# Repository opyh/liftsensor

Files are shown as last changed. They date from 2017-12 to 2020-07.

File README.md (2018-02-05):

# liftsensor

Measures acceleration to find out if an elevator works and updates its status on [accessibility.cloud](https://www.accessibility.cloud).

## Design / photos

This is how the sensor looks:

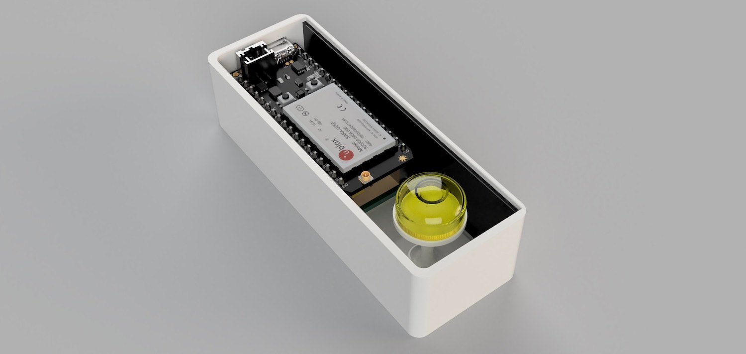
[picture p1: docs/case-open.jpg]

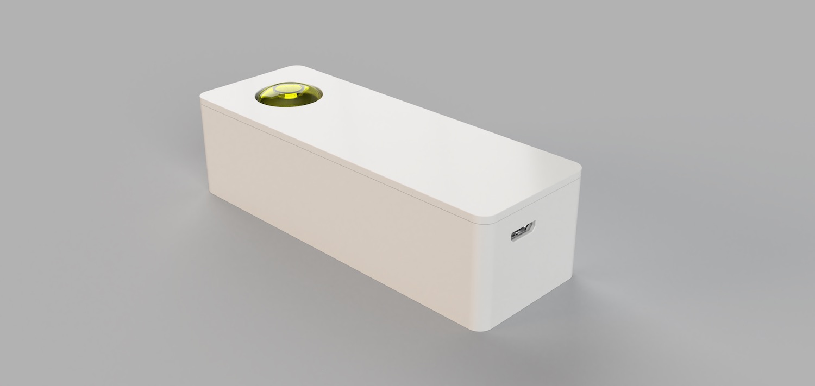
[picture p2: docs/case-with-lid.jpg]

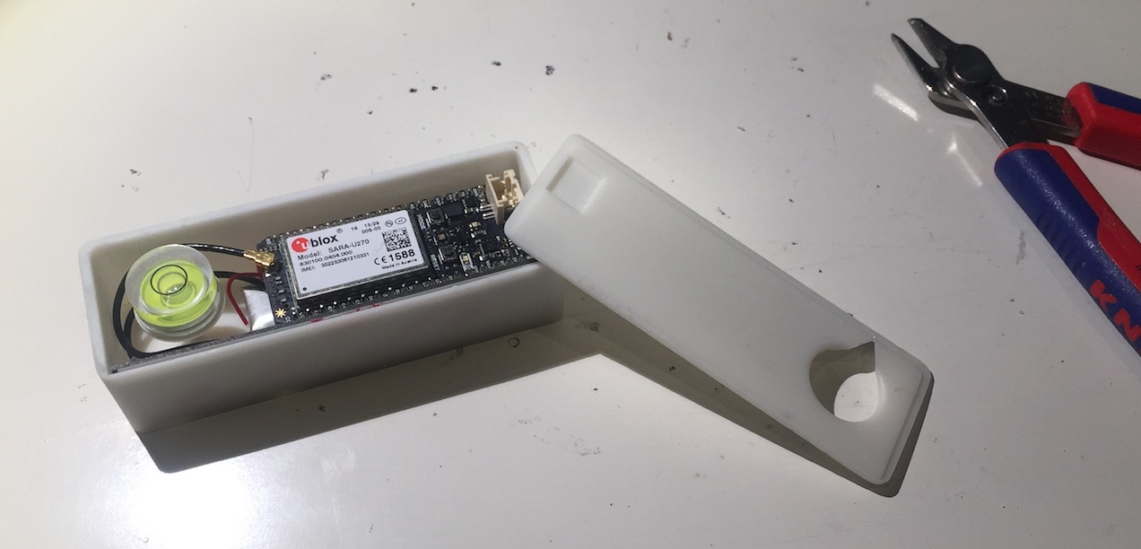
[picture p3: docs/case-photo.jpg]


## Technical specification

- Plug & Play installation using the maintenance 230V AC connector on top of the elevator's cabin
- Typical power consumption <1W, micro USB power adapter
- Sets the elevator's status to 'unknown' on [accessibility.cloud](https://www.accessibility.cloud) if it has not been in use within typical usage time intervals
- M2M Nano SIM card leverages a comprehensive network of carriers to provide service in over 100 countries out of the box
- Built-in 150mA battery to actively send a maintenance event in case the device is actively unplugged
- Open source design based on [Particle Electron](https://docs.particle.io/datasheets/electron-(cellular)/electron-datasheet/) IoT platform
- Analog Devices ADXL335 3-Axis ±3 g acceleration sensor
- U-blox SARA-U260/U270 3G module for communication with [accessibility.cloud](https://www.accessibility.cloud)
- STM32F205RGT6 120MHz ARM Cortex M3 microcontroller
- 1MB flash, 128KB RAM
- Allows firmware updates over-the-air
- RGB status LED
- Real-time operation system (RTOS)

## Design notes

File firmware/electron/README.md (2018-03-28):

# liftsensor

A hardware part of [Projekt Elevate](https://www.projekt-elevate.de) by
[Sozialhelden e.V.](https://sozialhelden.de).

## Setup

- Use a [Particle Electron](https://docs.particle.io/guide/getting-started/intro/electron/) as
  hardware
- Current development configuration is for Visual Studio Code on Mac. For other platforms, please
  extend this file ✍️
- Install the [po](https://github.com/nrobinson2000/po) utility. This will download the necessary
  dependencies automatically.
- Be sure to install the right GCC version:
    ```bash
    brew install nrobinson2000/newpo/gcc-arm-none-eabi-53
    brew link --overwrite nrobinson2000/newpo/gcc-arm-none-eabi-53
    ```

## How to run it

- Build with the configured build task, start with one of the configured test tasks

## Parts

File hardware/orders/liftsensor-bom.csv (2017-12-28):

Designator | Manufacturer Part Number | Quantity | Unit Price
C1,C2,C3,C4 | C0402C104K9PACTU | 4 | 0.02080
U1 | ADXL335BCPZ | 1 | 5.54000
JP1 | 0901210762 | 1 | 2.25000
EL | 6-535541-6 | 2 | 0.23

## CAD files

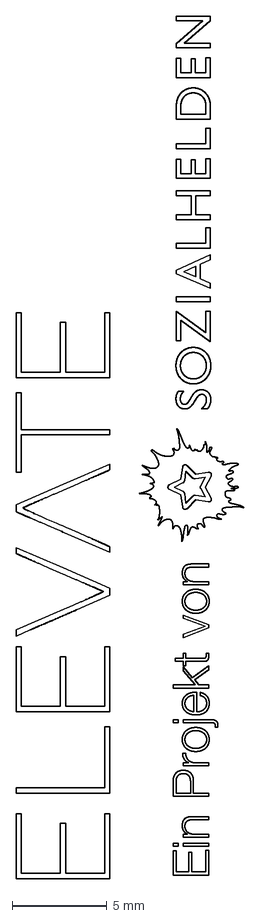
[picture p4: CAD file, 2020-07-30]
hardware/Lift sensor top logos.dxf
12.0 x 45.6 mm

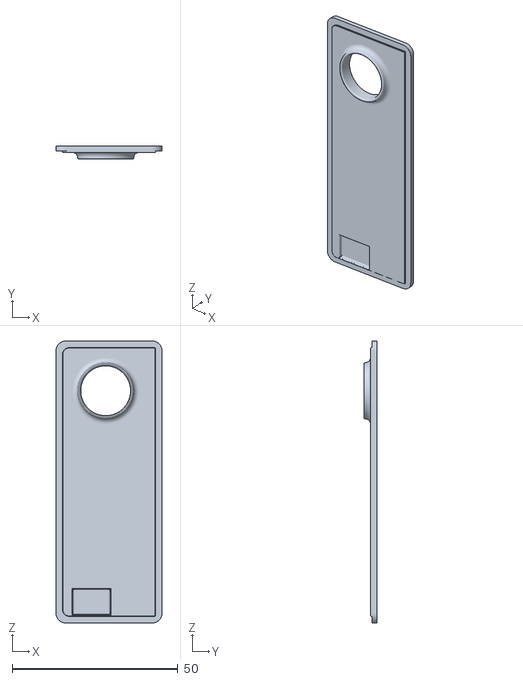
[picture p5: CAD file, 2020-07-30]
hardware/Liftsensor Case Top.stl
32.0 x 4.00 x 85.0

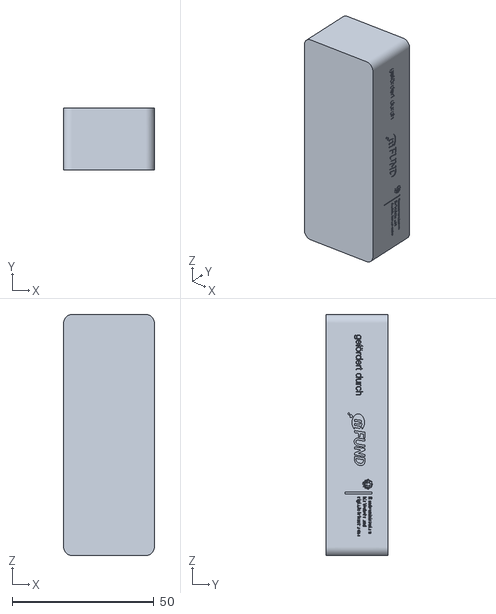
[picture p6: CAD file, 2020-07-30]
hardware/Liftsensor Case Body2.stl
32.0 x 22.0 x 85.0

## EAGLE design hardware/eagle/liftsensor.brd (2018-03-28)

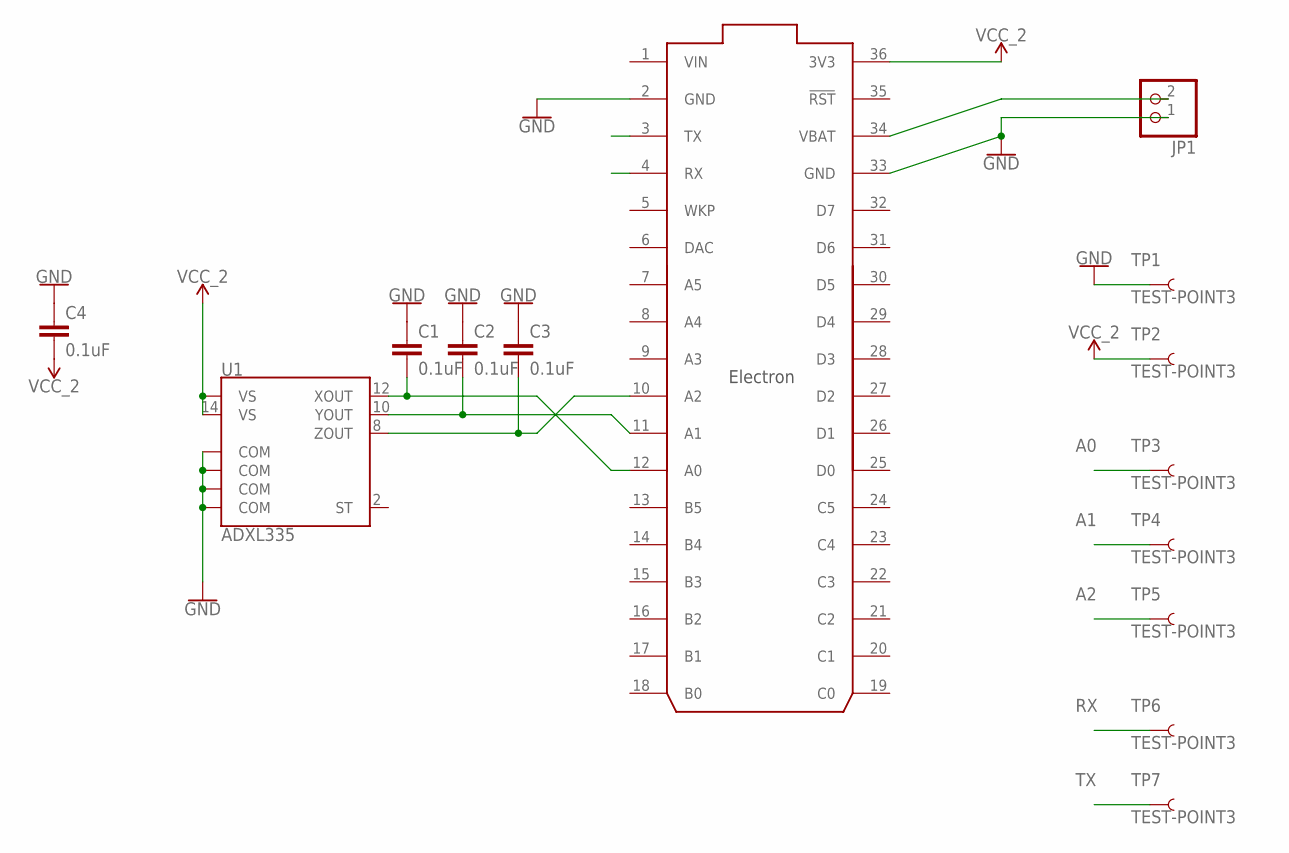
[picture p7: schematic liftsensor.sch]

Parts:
C1, C2, C3, C4: 0.1uF; 0603
EL: ELECTRON_WITH_HEADERS; ELECTRON
JP1: PINHD-1X2/90; 1X02/90
TP1, TP2, TP3, TP4, TP5, TP6, TP7: TEST-POINT3; PAD.03X.03
U1: ADXL335; LFCSP-16-4X4

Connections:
A0: C1.2, EL.12 (A0), TP3.P$1, U1.12 (XOUT)
A1: C2.2, EL.11 (A1), TP4.P$1, U1.10 (YOUT)
A2: C3.2, EL.10 (A2), TP5.P$1, U1.8 (ZOUT)
GND: C1.1, C2.1, C3.1, C4.1, EL.2 (GND), EL.33 (GND), JP1.1, TP1.P$1, U1.3 (COM), U1.5 (COM), U1.6 (COM), U1.7 (COM)
RX: EL.4 (RX), TP6.P$1
TX: EL.3 (TX), TP7.P$1
VBAT: EL.34 (VBAT), JP1.2
VCC_2: C4.2, EL.36 (3V3), TP2.P$1, U1.14 (VS), U1.15 (VS)
VIN: EL.1 (VIN)

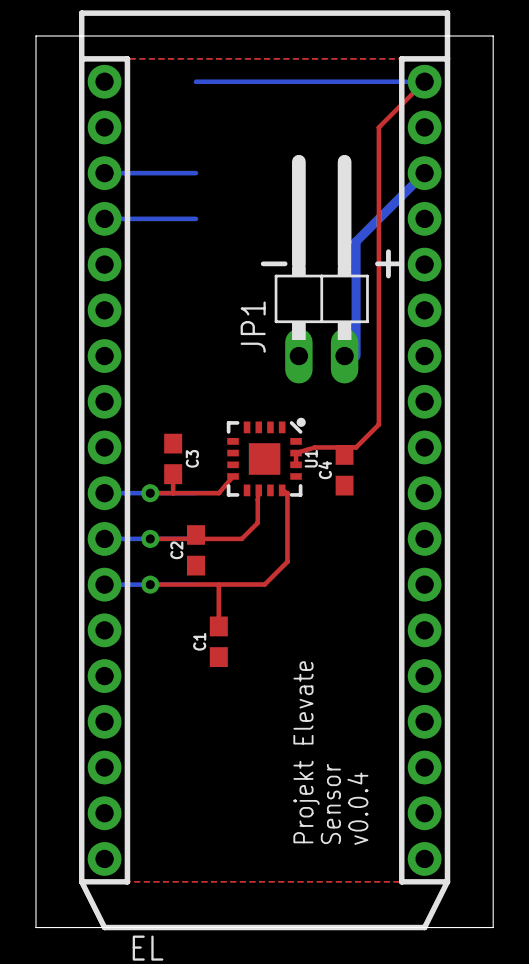
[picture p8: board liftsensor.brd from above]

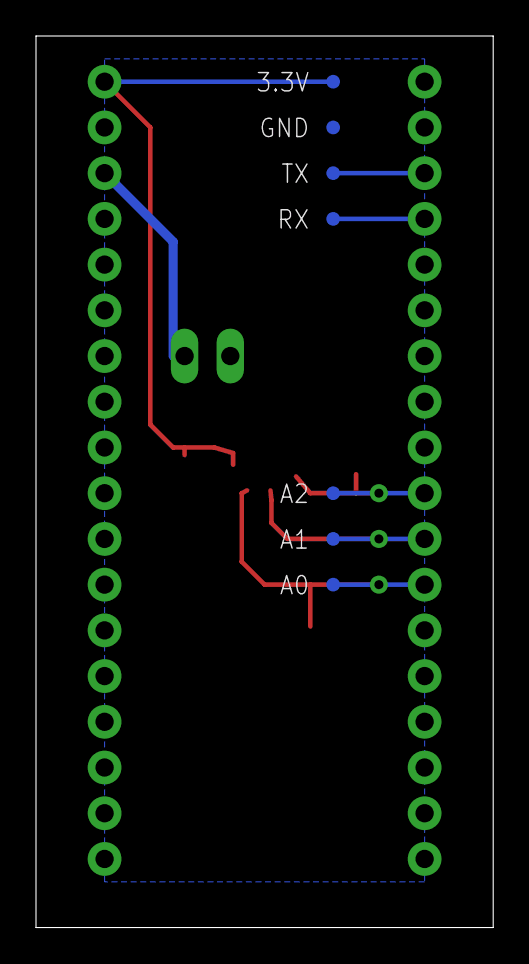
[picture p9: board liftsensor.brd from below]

Board: 2 copper layers, 25.4 x 49.5 mm, 14 parts (7 on the bottom side), 8 nets.

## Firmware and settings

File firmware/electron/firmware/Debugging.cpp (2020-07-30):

// MIT License
//
// Copyright (c) 2016 rickkas7
//
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
// Electron Sample Application for fault tolerance and problem debugging techniques
// Requires system firmware 0.5.0 or later!
//
// Original code location:
// https://github.com/rickkas7/electronsample

#include "Particle.h"

// If you are using a 3rd party SIM card, put your APN here. See also
// the call to Particle.keepAlive in setup()
// STARTUP(cellular_credentials_set("YOUR_APN_GOES_HERE", "", "", NULL));

// We use retained memory keep track of connection events; these are saved and later uploaded
// to the cloud even after rebooting
STARTUP(System.enableFeature(FEATURE_RETAINED_MEMORY));

// System threaded mode is not required here, but it's a good idea with 0.5.0 and later.
// https://docs.particle.io/reference/firmware/electron/#system-thread
SYSTEM_THREAD(ENABLED);

// SEMI_AUTOMATIC mode or system thread enabled is required here, otherwise we can't
// detect a failure to connect
// https://docs.particle.io/reference/firmware/electron/#semi-automatic-mode
SYSTEM_MODE(SEMI_AUTOMATIC);

namespace Debugging {

// Various settings for how long to wait before rebooting and so forth
const unsigned long LISTEN_WAIT_FOR_REBOOT = 30000; // milliseconds, 0 = don't reboot on entering listening mode
const unsigned long CLOUD_WAIT_FOR_REBOOT = 300000; // milliseconds, 0 = don't reboot
const unsigned long PUBLISH_RATE_LIMIT = 1010; // milliseconds; to avoid sending events too rapidly
const unsigned long PING_TIMEOUT = 180000; // milliseconds
const unsigned long APP_WATCHDOG_TIMEOUT = 300000; // milliseconds
const uint8_t NUM_REBOOTS_BEFORE_RESETTING_MODEM = 3; //
const size_t MAX_TESTERFN_ARGS = 5; // Used to split out arguments to testerFn Particle.function
const int SLEEP_TEST_PIN = D2; // Used for testing sleep with pin modes

// This code is used to track connection events, used mainly for debugging
// and making sure this code works properly.
const size_t CONNECTION_EVENT_MAX = 32; // Maximum number of events to queue, 16 bytes each
const unsigned long CONNECTION_EVENT_MAGIC = 0x5c39d415;

// This is the event that's used to publish data to your event log. It's sent in PRIVATE mode.
const char *CONNECTION_EVENT_NAME = "connEventStats";

// These are the defined event codes. Instead of a string, they're sent as an integer to make
// the output more compact, saving retained memory and allowing more events to fit in a Particle.publish/
enum ConnectionEventCode {
	CONNECTION_EVENT_SETUP_STARTED = 0,		// 0
	CONNECTION_EVENT_CELLULAR_READY,		// 1
	CONNECTION_EVENT_CLOUD_CONNECTED,		// 2
	CONNECTION_EVENT_LISTENING_ENTERED,		// 3
	CONNECTION_EVENT_MODEM_RESET,			// 4
	CONNECTION_EVENT_REBOOT_LISTENING,		// 5
	CONNECTION_EVENT_REBOOT_NO_CLOUD,		// 6
	CONNECTION_EVENT_PING_DNS,				// 7
	CONNECTION_EVENT_PING_API,				// 8
	CONNECTION_EVENT_APP_WATCHDOG,			// 9
	CONNECTION_EVENT_TESTERFN_REBOOT,		// 10
	CONNECTION_EVENT_TESTERFN_APP_WATCHDOG,	// 11
	CONNECTION_EVENT_SLEEP					// 12
};

// Data for each event is stored in this structure
typedef struct { // 16 bytes per event
	unsigned long tsDate;
	unsigned long tsMillis;
	int eventCode;
	int data;
} ConnectionEventInfo;

// This structure is what's stored in retained memory
typedef struct {
	unsigned long eventMagic; // CONNECTION_EVENT_MAGIC
	uint8_t numFailureReboots;
	uint8_t reserved3;
	uint8_t reserved2;
	uint8_t reserved1;
	size_t eventCount;
	ConnectionEventInfo events[CONNECTION_EVENT_MAX];
} ConnectionEventData;

// This is where the retained memory is allocated. Currently 522 bytes.
// There are checks in connectionEventSetup() to initialize it on first
// use and if the format changes dramatically.
retained ConnectionEventData connectionEventData;

// This is used to slow down publishing of data to once every 1010 milliseconds to avoid
// exceeding the publish rate limit.
unsigned long connectionEventLastSent = 0;

void connectionEventSetup(); // forward declaration
void connectionEventLoop(); // forward declaration
void connectionEventAdd(int eventCode, int data = 0); // forward declaration


// This code is to handle keeping track of connection state and rebooting if necessary

bool cloudConnectDebug(); // forward declaration
void smartReboot(int reason, bool forceResetModem); // forward declaration
void watchdogCallback(); // forward declaration
int testerFnCallback(String arg); // forward declaration
void testerFnLoopHandler(char *mutableData); // forward declaration

bool isCellularReady = false;
bool isCloudConnected = false;
unsigned long listeningStart = 0;
unsigned long cloudCheckStart = 0;
char *testerFnLoopData = NULL;

// Optional: Initialize the Application Watchdog. This runs as a separate thread so if you
// block the main loop thread for more than APP_WATCHDOG_TIMEOUT milliseconds, the callback
// will be called. This currently logs an event in retained memory then resets.
// When the Electron reboots and comes back online, these events will be published.
// https://docs.particle.io/reference/firmware/electron/#application-watchdog
ApplicationWatchdog wd(APP_WATCHDOG_TIMEOUT, watchdogCallback);


void setup() {
	// We store connection events in retained memory
	connectionEventSetup();


	// This function is used only for tested, so you can trigger the various things
	// like reset, modemReset, and appWatchdog for testing purposes
	Particle.function("testerFn", testerFnCallback);

	// If you are using a 3rd party SIM card, you will likely have to set this
	// https://docs.particle.io/reference/firmware/electron/#particle-keepalive-
	// Particle.keepAlive(180);

	// This is used only for sleep with pin tests using testerFn
	pinMode(SLEEP_TEST_PIN, INPUT_PULLUP);

	// We use semi-automatic mode so we can disconnect if we want to, but basically we
	// use it like automatic, as we always connect initially.
	Particle.connect();
}

void loop() {

	// Check cellular status - used for event logging mostly
	bool temp = Cellular.ready();
	if (temp != isCellularReady) {
		// Cellular state changed
		isCellularReady = temp;
		connectionEventAdd(CONNECTION_EVENT_CELLULAR_READY, isCellularReady);
		Serial.printlnf("cellular %s", isCellularReady ? "up" : "down");
	}

	// Check cloud connection status
	temp = Particle.connected();
	if (temp != isCloudConnected) {
		// Cloud connection state changed
		isCloudConnected = temp;
		connectionEventAdd(CONNECTION_EVENT_CLOUD_CONNECTED, isCloudConnected);
		Serial.printlnf("cloud connection %s", isCloudConnected ? "up" : "down");

		if (isCloudConnected) {
			// After successfully connecting to the cloud, clear the failure reboot counter
			connectionEventData.numFailureReboots = 0;
		}
		else {
			// Cloud just disconnected, start measuring how long we've been disconnected
			cloudCheckStart = millis();
		}
	}

	if (!isCloudConnected) {
		// Not connected to the cloud - check to see if we've spent long enough in this state to reboot
		if (CLOUD_WAIT_FOR_REBOOT != 0 && millis() - cloudCheckStart >= CLOUD_WAIT_FOR_REBOOT) {
			// The time to wait to connect to the cloud has expired, reboot

			bool forceResetModem = false;

			if (isCellularReady) {
				// Generate events about the state of the connection before rebooting. We also
				// do some ping tests, and if we can't successfully ping, we force reset the mode
				// in hopes to clear this problem more quickly.
				forceResetModem = cloudConnectDebug();
			}

			// Reboot
			smartReboot(CONNECTION_EVENT_REBOOT_NO_CLOUD, forceResetModem);
		}
	}


	if (Cellular.listening()) {
		// Entered listening mode (blinking blue). Could be from holding down the MODE button, or
		// by repeated connection failures, see: https://github.com/spark/firmware/issues/687
		if (listeningStart == 0) {
			listeningStart = millis();
			connectionEventAdd(CONNECTION_EVENT_LISTENING_ENTERED);
			Serial.println("entered listening mode");
		}
		else {
			if (LISTEN_WAIT_FOR_REBOOT != 0 && millis() - listeningStart >= LISTEN_WAIT_FOR_REBOOT) {
				// Reboot
				smartReboot(CONNECTION_EVENT_REBOOT_LISTENING, false);
			}
		}
	}

	if (testerFnLoopData != NULL) {
		char *mutableData = testerFnLoopData;
		testerFnLoopData = NULL;

		testerFnLoopHandler(mutableData);

		free(mutableData);
	}

	// Handle sending out saved events
	connectionEventLoop();
}

// reason is the reason code, one of the CONNECTION_EVENT_* constants
// forceResetMode will reset the modem even immediately instead of waiting for multiple failures
void smartReboot(int reason, bool forceResetModem) {
	connectionEventAdd(reason, ++connectionEventData.numFailureReboots);
	Serial.printlnf("smartReboot reason=%d numFailureReboots=%d forceResetModem=%d", reason, connectionEventData.numFailureReboots, forceResetModem);

	if (connectionEventData.numFailureReboots >= NUM_REBOOTS_BEFORE_RESETTING_MODEM || forceResetModem) {
		// We try not to do this because it requires the cellular handshake process to repeat,
		// which takes time and data.
		// This makes the reset more like unplugging the battery and power and doing a cold restart.
		connectionEventAdd(CONNECTION_EVENT_MODEM_RESET);
		connectionEventData.numFailureReboots = 0;

		Serial.println("resetting modem");

		Particle.disconnect();

		// 16:MT silent reset (with detach from network and saving of NVM parameters), with reset of the SIM card
		Cellular.command(30000, "AT+CFUN=16\r\n");

		Cellular.off();

		delay(1000);
	}

	System.reset();
}

// This is called when timing out connecting to the cloud. It adds some debugging events to
// help log the current state for debugging purposes.
// It returns true to force a modem reset immediately, false to use the normal logic for whether to reset the modem.
bool cloudConnectDebug() {
	int res = Cellular.command(PING_TIMEOUT, "AT+UPING=8.8.8.8\r\n");
	connectionEventAdd(CONNECTION_EVENT_PING_DNS, res);

	res = Cellular.command(PING_TIMEOUT, "AT+UPING=api.particle.io\r\n");
	connectionEventAdd(CONNECTION_EVENT_PING_API, res);

	// If pinging api.particle.io does not succeed, then reboot the modem right away
	return (res != RESP_OK);
}

// Called from the application watchdog when the main loop is blocked
void watchdogCallback() {
	// This isn't quite safe; connectionEventAdd should only be called from the main loop thread,
	// but since by definition the main loop thread is stuck when the app watchdog fires, this is
	// probably not that unsafe. (The application watchdog runs in a separate thread.)
	connectionEventAdd(CONNECTION_EVENT_APP_WATCHDOG);
	System.reset();
}

// This is the function registered with Particle.function(). Just copy the data and return so
// the successful response can be returned to the caller. Since we do things like reset, or
// enter an infinite loop, or sleep, doing this right from the callback causes the caller to
// time out because the response will never be received.
int testerFnCallback(String argStr) {
	// Process this in loop so the function won't time out
	testerFnLoopData = strdup(argStr.c_str());

	return 0;
}

// This does the actual work from the Particle.function(). It's called from looo().
void testerFnLoopHandler(char *mutableData) {
	// Parse argument into space-separated fields
	const char *argv[MAX_TESTERFN_ARGS];
	size_t argc = 0;

	char *cp = strtok(mutableData, " ");
	while(cp && argc < MAX_TESTERFN_ARGS) {
		argv[argc++] = cp;
		cp = strtok(NULL, " ");
	}
	if (argc == 0) {
		// No parameter, nothing to do
		return;
	}

	// Delay a bit here to make sure the function result is returned, otherwise if we
	// immediately go to sleep the function may return a timeout error.
	delay(500);

	// Process options here
	if (strcmp(argv[0], "reset") == 0) {
		smartReboot(CONNECTION_EVENT_TESTERFN_REBOOT, false);
	}
	else
	if (strcmp(argv[0], "modemReset") == 0) {
		smartReboot(CONNECTION_EVENT_TESTERFN_REBOOT, true);
	}
	else
	if (strcmp(argv[0], "appWatchdog") == 0) {
		connectionEventAdd(CONNECTION_EVENT_TESTERFN_APP_WATCHDOG, APP_WATCHDOG_TIMEOUT);

		while(true) {
			// Infinite loop!
		}
	}
	else
	if (strcmp(argv[0], "sleep") == 0 && argc >= 2) {
		// example usage from the Particle CLI:
		// particle call electron2 testerFn "sleep networkStandby 15"

		// optional duration in seconds, if not specified the default is 30
		int duration = 30;
		if (argc >= 3) {
			duration = atoi(argv[2]);
			if (duration == 0) {
				duration = 30;
			}
		}

		connectionEventAdd(CONNECTION_EVENT_SLEEP);

		if (strcmp(argv[1], "deep") == 0) {
			// SLEEP_MODE_DEEP requires cellular handshaking again (blinking green) and also
			// restarts running setup() again, so you'll get an event 0 (CONNECTION_EVENT_SETUP_STARTED)
			System.sleep(SLEEP_MODE_DEEP, duration);
		}
		else
		if (strcmp(argv[1], "stop") == 0) {
			// stop mode sleep stops the processor but execution will continue in loop() without going through setup again
			// This mode will shut down the cellular modem to save power so upon wake it requires cellular handshaking
			// again (blinking green)
			System.sleep(SLEEP_TEST_PIN, FALLING, duration);
		}
		else
		if (strcmp(argv[1], "networkStandby") == 0) {
			// stop mode sleep stops the processor but execution will continue in loop() without going through setup again
			// This mode keeps the cellular modem alive, so you should go right back into blinking cyan to handshake
			// to the cloud only
			System.sleep(SLEEP_TEST_PIN, FALLING, duration, SLEEP_NETWORK_STANDBY);
		}
	}
}

//
// Connection Event Code
//
// The idea is that we store small (16 byte) records of data in retained memory so they are preserved across rebooting
// the Electron. Then, when we get online, we publish these records so they'll be found in your event log.
//
// The event data might look like this:
//
// 1470912225,52,0,0;1470912226,1642,1,1;1470912228,3630,2,1;
//
// Each record, corresponding to a ConnectionEventInfo object consists of 4 comma-separated fields:
// date and time (Unix date format, seconds past January 1, 1970; the value returned by Time.now())
// millis() value
// eventCode - one of the CONNECTION_EVENT_* constants defined above
// data - depends on the event code
//
// Multiple records are packed into a single event up to the maximum event size (256 bytes); they are
// separated by semicolons.
//

// This should be called during setup()
void connectionEventSetup() {
	if (connectionEventData.eventMagic != CONNECTION_EVENT_MAGIC ||
		connectionEventData.eventCount > CONNECTION_EVENT_MAX) {
		//
		Serial.println("initializing connection event retained memory");
		connectionEventData.eventMagic = CONNECTION_EVENT_MAGIC;
		connectionEventData.eventCount = 0;
		connectionEventData.numFailureReboots = 0;
	}
	connectionEventAdd(CONNECTION_EVENT_SETUP_STARTED);
}

// This should be called from loop()
// If there are queued events and there is a cloud connection they're published, oldest first.
void connectionEventLoop() {
	if (connectionEventData.eventCount == 0) {
		// No events to send
		return;
	}

	if (!Particle.connected()) {
		// Not cloud connected, can't publish
		return;
	}

	if (millis() - connectionEventLastSent < PUBLISH_RATE_LIMIT) {
		// Need to wait before sending again to avoid exceeding publish limits
		return;
	}

	// Send events
	char buf[256]; // 255 data bytes, plus null-terminator
	size_t numHandled;
	size_t offset = 0;

	// Pack as many events as we have, up to what will fit in a 255 byte publish
	for(numHandled = 0; numHandled < connectionEventData.eventCount; numHandled++) {
		char entryBuf[64];

		ConnectionEventInfo *ev = &connectionEventData.events[numHandled];
		size_t len = snprintf(entryBuf, sizeof(entryBuf), "%lu,%lu,%d,%d;", ev->tsDate, ev->tsMillis, ev->eventCode, ev->data);
		if ((offset + len) >= sizeof(buf)) {
			// Not enough buffer space to send in this publish; try again later
			break;
		}
		strcpy(&buf[offset], entryBuf);
		offset += len;
	}
	connectionEventData.eventCount -= numHandled;
	if (connectionEventData.eventCount > 0) {
		Serial.printlnf("couldn't send all events, saving %d for later", connectionEventData.eventCount);
		memmove(&connectionEventData.events[0], &connectionEventData.events[numHandled], connectionEventData.eventCount * sizeof(ConnectionEventData));
	}
	else {
		Serial.printlnf("sent %d events", numHandled);
	}

	Particle.publish(CONNECTION_EVENT_NAME, buf, PRIVATE);
	connectionEventLastSent = millis();
}

// Add a new event. This should only be called from the main loop thread.
// Do not call from other threads like the system thread, software timer, or interrupt service routine.
void connectionEventAdd(int eventCode, int data /* = 0 */) {
	if (connectionEventData.eventCount >= CONNECTION_EVENT_MAX) {
		// Throw out oldest event
		Serial.println("discarding old event");
		connectionEventData.eventCount--;
		memmove(&connectionEventData.events[0], &connectionEventData.events[1], connectionEventData.eventCount * sizeof(ConnectionEventData));
	}

	// Add new event
	ConnectionEventInfo *ev = &connectionEventData.events[connectionEventData.eventCount++];
	ev->tsDate = Time.now();
	ev->tsMillis = millis();
	ev->eventCode = eventCode;
	ev->data = data;

	Serial.printlnf("connectionEvent event=%d data=%d", eventCode, data);
}


}

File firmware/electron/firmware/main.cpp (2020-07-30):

#include "Particle.h"
#include "math.h"

#include "Battery.h"
#include "SensorDriver.h"
#include "NetworkDriver.h"
#include "RootController.h"
#include "Debugging.h"

const time_t mainLoopDelay = 10;

PRODUCT_ID(7299);
PRODUCT_VERSION(3);

// PMIC().disableCharging();
Battery battery = Battery();
SensorDriver sensorDriver = SensorDriver();
NetworkDriver networkDriver = NetworkDriver();
RootController rootController = RootController(battery, sensorDriver, networkDriver);

void setup() {
    Serial.begin(115200);
    Debugging::setup();
    Particle.variable("loopDelay", mainLoopDelay);
    rootController.init();
}


void loop() {
    Debugging::loop();
    delay(mainLoopDelay);
    rootController.process();
}

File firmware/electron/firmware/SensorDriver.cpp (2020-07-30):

#include "Particle.h"
#include <math.h>

#include "SensorDriver.h"

// int setThresholdInG(String newTime) {
//     thresholdInG = newTime.toFloat();
//     return 0;
// }


SensorDriver::SensorDriver() {
}


double SensorDriver::voltageFromPinValue(int pinValue) {
    return (SupplyVoltage * pinValue / AnalogResolution);
}


double SensorDriver::accelerationFromPinValue(size_t axisIndex, int pinValue) {
    double volts = voltageFromPinValue(pinValue) - AxisBiasVoltages[axisIndex];
    return volts / VoltsPerG;
}


double SensorDriver::getDCFilteredSpeed() {
    return smoothenedFilteredAccumulatedSpeeds[2];
}

bool SensorDriver::isOverSpeedThreshold() {
    return fabs((float) getDCFilteredSpeed()) > SpeedThreshold;
}

void SensorDriver::updateMaxSpeed() {
    auto speed = getDCFilteredSpeed();
    if (fabs((float) speed) > fabs((float) maxSpeed)) {
        maxSpeed = speed;
    }
}


void SensorDriver::setCloudVariables() {
    Particle.variable("x", smoothenedAccelerations[0]);
    Particle.variable("y", smoothenedAccelerations[1]);
    Particle.variable("z", smoothenedAccelerations[2]);
    Particle.variable("speed", smoothenedFilteredAccumulatedSpeeds[2]);
    Particle.variable("maxSpeed", maxSpeed);
}


void SensorDriver::setupFirstAverageValue() {
    measure();
    for (size_t i = 0; i < NUMBER_OF_AXES; i++) {
        smoothenedAccelerations[i] = accelerations[i];
        dcFilteredSpeeds[i] = 0;
        smoothenedDCFilteredSpeeds[i] = 0;
        dcFilteredAveragedDCFilteredSpeeds[i] = 0;
        smoothenedFilteredAccumulatedSpeeds[i] = 0;
    }
}


void SensorDriver::init() {
    // Longer sample time for smoother values
    setADCSampleTime(ADC_SampleTime_480Cycles);
    setupFirstAverageValue();
}


void SensorDriver::measureOneAxis(size_t index, int pin) {
    pinValues[index] = analogRead(pin);
    accelerations[index] = accelerationFromPinValue(index, pinValues[index]);
    smoothenedAccelerations[index] =
        ExponentialAverageAlpha * accelerations[index] +
        (1.0 - ExponentialAverageAlpha) * smoothenedAccelerations[index];

    // 1. Accumulating past acceleration values to calculate speed. Filter out gravity first using
    // a DC bias filter

    dcFilteredSpeeds[index] += accelerations[index] - smoothenedAccelerations[index];

    // 2. average signal to remove high-frequency noise. Without this, a sudden movement like a
    // train passing nearby or an entering passenger could cause an overshoot event.

    smoothenedDCFilteredSpeeds[index] =
        ExponentialAverageAlpha * dcFilteredSpeeds[index] +
        (1.0 - ExponentialAverageAlpha) * smoothenedDCFilteredSpeeds[index];

    // 3. The signal still has a DC bias. Remove it.

    dcFilteredAveragedDCFilteredSpeeds[index] = dcFilteredSpeeds[index] - smoothenedDCFilteredSpeeds[index];

    // 4. Another low-pass filter to remove jitter.

    smoothenedFilteredAccumulatedSpeeds[index] =
            ExponentialAverageAlpha * dcFilteredAveragedDCFilteredSpeeds[index] +
        (1.0 - ExponentialAverageAlpha) * smoothenedFilteredAccumulatedSpeeds[index];

}


void SensorDriver::measure() {
    measureOneAxis(0, A0);
    measureOneAxis(1, A1);
    measureOneAxis(2, A2);
    updateMaxSpeed();
}


void SensorDriver::process(time_t now) {
    measure();
    setCloudVariables();
    printStatus();
}

void SensorDriver::printStatus() {
    // Debouncing
    auto now = millis();
    if (now - lastPrintTime < 500) return;
    lastPrintTime = now;

    Serial.printf("\r");
    for (size_t i = 0; i < NUMBER_OF_AXES; i++) {
        Serial.printf(
            "%c %.2fV %+.2fg %+.2fg %+.2fg  │  ",
            'x' + i,
            voltageFromPinValue(pinValues[i]),
            accelerations[i],
            smoothenedAccelerations[i],
            accelerations[i] - smoothenedAccelerations[i]
        );
    }

    Serial.printf(
        " -> v = %+.2f / %+.2f",
        dcFilteredAveragedDCFilteredSpeeds[2],
        smoothenedFilteredAccumulatedSpeeds[2]
    );
}

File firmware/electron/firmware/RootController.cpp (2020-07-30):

#include "RootController.h"
#include "math.h"
#include "Diagnostics.h"
#include "TimeUtil.h"
#include "Settings.h"

bool locationRequested = false;


int locate(String args)
{
	locationRequested = true;
	return 1;
}

int sendNetworkRegistrationStatus(String args) {
	Diagnostics::sendNetworkRegistrationStatus();
	return 0;
}


RootController::RootController(Battery &_battery, SensorDriver &_sensorDriver, NetworkDriver &_networkDriver)
:
	StateMachine(StateConnecting, "Core"),
	lastError(NULL),
	battery(_battery),
	sensorDriver(_sensorDriver),
	networkDriver(_networkDriver)
{

}


void RootController::init()
{
	delay(3000);
	Serial.println("\r\n\n\n\n\n[Core] Initializing magic... ✨ ");
	Serial.print("[Core] Hello, I am ");
	Serial.print(Particle.deviceID());
	Serial.println("!");
	Particle.function("locate", locate);
	Particle.function("net", sendNetworkRegistrationStatus);
	Settings::setupEEPROMFunctions();
	sensorDriver.init();
	networkDriver.init();
	battery.init();
}


void RootController::process()
{
	StateMachine::process();
	time_t now = millis();
	sensorDriver.process(now);
	networkDriver.process(now);
    battery.process(now);
}



void RootController::processState()
{
	if (locationRequested)
	{
		setState(StateLocating);
		locationRequested = false;
		return;
	}

	switch (state)
	{
		case StateConnecting:
			setStateAfter(StateSendingCellularDiagnostics, 500);
			break;
		case StateSendingCellularDiagnostics:
			setStateAfter(StateWaitingForOvershot, 5000);
			break;
		case StateInactive:
			if (sensorDriver.isOverSpeedThreshold()) setState(StateMeasuringPaused);
			// Exponential backoff
			setStateAfter(StateInactive, intervalForInactivityEventMs);
			break;
		case StateWaitingForOvershot:
			if (sensorDriver.isOverSpeedThreshold()) {
				setState(StateMeasuringPaused);
			}
			setStateAfter(StateInactive, IntervalForDetectingInactivityMs);
			break;
		case StateMeasuringPaused:
			setStateAfter(StateWaitingForOvershot, OvershotDetectionPauseIntervalMs);
			break;
		case StateError:
			setStateAfter(StateSendingCellularDiagnostics, intervalForErrorEventMs);
			break;
	}
}


void RootController::enterState()
{
	if (state != lastState && state != StateConnecting)
	{
		sendCurrentStateEvent();
	}

	switch (state)
	{
		case StateSendingCellularDiagnostics:
			Diagnostics::sendCellularDiagnostics();
			break;
		case StateLocating:
			// startLocating();
			break;
		case StateWaitingForOvershot:
			sensorDriver.setupFirstAverageValue();
			break;
		case StateMeasuringPaused:
			sendOvershootEvent();
		    intervalForInactivityEventMs = FirstIntervalForInactivityEventMs;
			break;
		case StateInactive: {
			const auto &settings = Settings::getFromEEPROM();
			String data = String::format(
				"{\"v\":0,\"s\":\"%s\",\"e\":\"%s\",\"t\":\"%s\",\"d\":%d}",
				settings.sourceId,
				settings.equipmentInfoId,
				settings.token,
				lastActivityMs ? int(0.001 * (millis() - lastActivityMs)) : -1
			);
			networkDriver.enqueueEvent("speed", data);


	        intervalForInactivityEventMs *= ExponentialBackoffFactorForInactivityEvent;
			Serial.print("\r\n[Core] Increased interval for inactivity events to ");
			printTime(Serial, intervalForInactivityEventMs);
			Serial.println();
		    Particle.variable("timeoutMs", intervalForInactivityEventMs);

			break;
		}
		case StateError:
			intervalForErrorEventMs *= 2;
			if (lastError)
			{
				Serial.print("\r\n[Core] Last error: ");
				Serial.print(lastError);
			}
			else
			{
				Serial.print("\r\n[Core] Unknown error.");
			}
			break;
	}
}


void RootController::exitState()
{
	switch (state)
	{
		case StateConnecting: break;
    	case StateSendingCellularDiagnostics: break;
		case StateLocating: break;
		case StateWaitingForOvershot: break;
		case StateMeasuringPaused: break;
		case StateInactive: break;
		case StateError: lastError = NULL; break;
	}
}


const char *RootController::nameForState(RootControllerState state)
{
	switch (state)
	{
		case StateConnecting: return "connecting to server";
		case StateSendingCellularDiagnostics: return "sending cellular info";
		case StateLocating: return "locating";
		case StateWaitingForOvershot: return "waiting for overshot";
		case StateMeasuringPaused: return "measuring paused";
		case StateInactive: return "inactive";
		case StateError: return "error";
	}

	return "Unknown state";
}


void RootController::sendCurrentStateEvent()
{
	const char *stateString = nameForState(state);
	Particle.variable("state", stateString, STRING);
	Particle.publish("diag/lastState", stateString, 3600, PRIVATE);
}


void RootController::sendOvershootEvent() {
	lastActivityMs = millis();
	const auto speed = sensorDriver.getDCFilteredSpeed();
	Serial.printlnf("\r\nSpeed threshold exceeded at %d, sending event with speed %0.4f", lastActivityMs, speed);

	const auto &settings = Settings::getFromEEPROM();
	String data = String::format(
		"{\"v\":%0.4f,\"s\":\"%s\",\"e\":\"%s\",\"t\":\"%s\",\"w\":true,\"d\":0}",
		speed,
		settings.sourceId,
		settings.equipmentInfoId,
		settings.token
	);
	networkDriver.enqueueEvent("speed", data);
}

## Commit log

2017-04-21 Add Fritzing schema for ADXL / Particle liftsensor
    [Liftsensor ADXL335.fzz]
2017-12-28 Add eagle files of first ordered board
    [liftsensor.GBL, liftsensor.GBO, liftsensor.GBP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]
2017-12-28 Order files in folders
    [Liftsensor ADXL335.fzz]
2017-12-28 Add first order BOM and gerber files
    [liftsensor-bom.csv]
2017-12-28 Fix bug in no-acceleration timeout handling
    [ElectronADXL335.ino, PhotonADXLWakeUpOnD0.ino]
2018-02-05 Update Eagle designs
    [liftsensor.brd, liftsensor.sch]
2018-03-28 Update hardware design with fixes, add ordered gerber files
    [liftsensor.GBL, liftsensor.GBO, liftsensor.GBP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]
2018-04-03 Improve code + measurement stability
    Make diagnostics easier:
    - Refactor code to use state machines
    - Send cell location + cell tower infos on device start
    - Filter measurements with a DC bias filter
    - Allow to use all axes for measurement in case of a faulty installation
    - Better measurement debouncing (fixed time window) and exponential backoff for inactivity events
    - Allow adding device modes in the future, for example for manual re-calibration
    [CellLocation.cpp]
2018-04-04 Cleanup, add more diagnostics code, more stable measurement
    - Remove obsolete functions/variables
    - Calculate speed from acceleration – speed thresholds catch elevator stopping/starting movements much better than accelerations and are more robust against noise like entering/existing passengers or trains
    - Queue events when there is no connection
    - Add more remote debugging code for diagnostics
    -
    [Debugging.cpp, RootController.cpp, SensorDriver.cpp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]
2020-07-30 Store settings in EEPROM + Battery handling
2020-07-30 Use correct DC-filtered speed value
    [SensorDriver.cpp]
2020-07-30 Add missing rootController.init() call
    [main.cpp]
2020-07-30 Add 3D print STL files
    [Liftsensor Case Body2.stl, Liftsensor Case Top.stl]
2020-07-30 Update top logos DXF
    [Lift sensor top logos.dxf]

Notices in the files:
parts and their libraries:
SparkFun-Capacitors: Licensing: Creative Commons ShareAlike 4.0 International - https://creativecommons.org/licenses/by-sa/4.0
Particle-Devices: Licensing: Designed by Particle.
